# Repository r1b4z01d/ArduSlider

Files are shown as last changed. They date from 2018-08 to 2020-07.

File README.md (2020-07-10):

*ArduSlider
** Arduino:
*** API:
The arduino expects each api call to consist of a letter (flag), set of numbers and a charige return. Example: B1000/n
In Flags: 
	T: Length of session in milliseconds
		T60000/n
	S: Sutter speed in milliseconds 
		S1000/n
	B: Length of time the cammera takes to save the image and clear it's buffer in milliseconds.
		B3000/n
	D: Distance of travel for the session in mm
		D1000/n
	R: Boolen trigger to start/stop the session.
		R1/n
	A: Request a full refresh of all parameters
		A/n 

Out:

  sendData("T",String(msOfCapture));
  sendData("P",String(photo));
  sendData("C",String(numPhotos));
  sendData("R",String(isRunning));
  sendData("S",String(shutterSpeed));
  sendData("B",String(bufferClear));
  sendData("D",String(mmOfTravel));
  sendData("L",String(totalSteps));

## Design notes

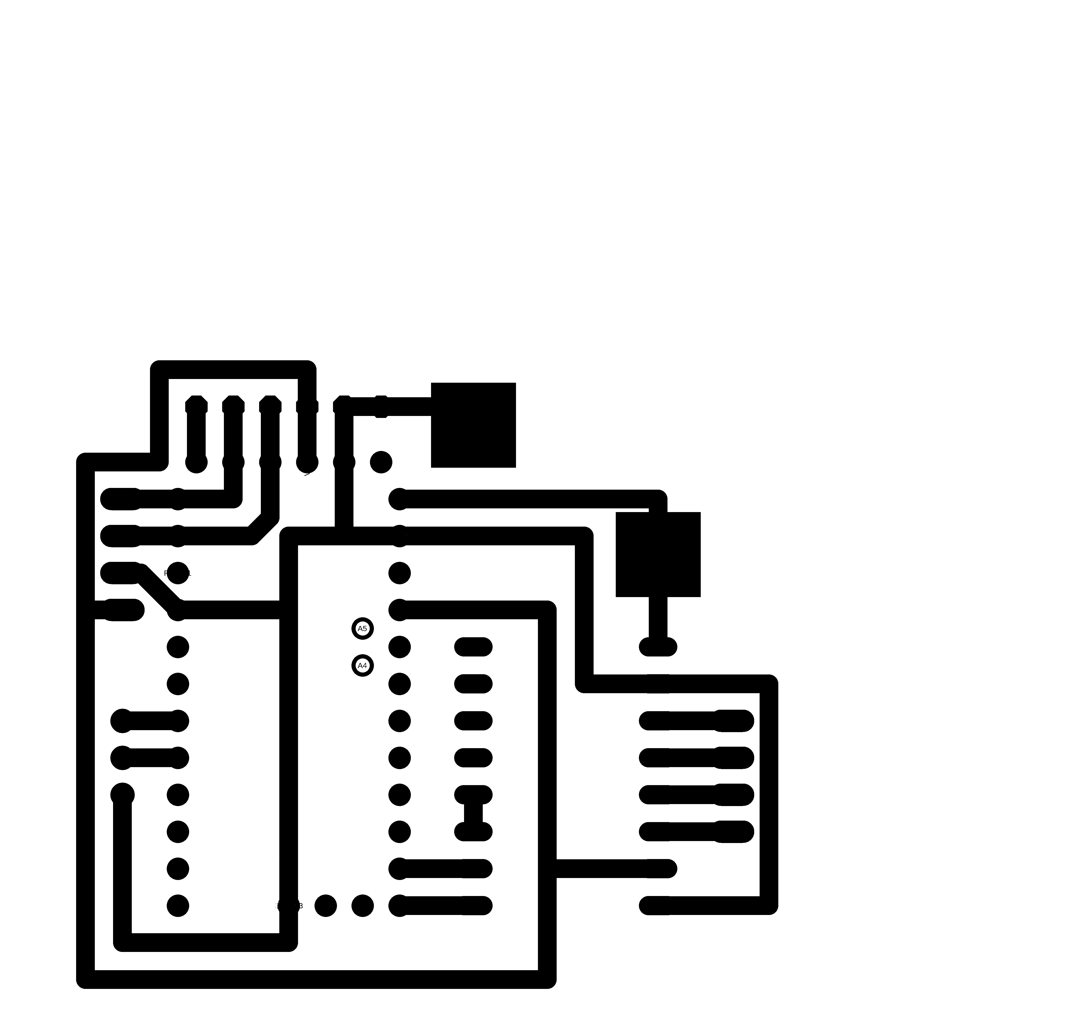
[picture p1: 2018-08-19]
PCB/pcb.png

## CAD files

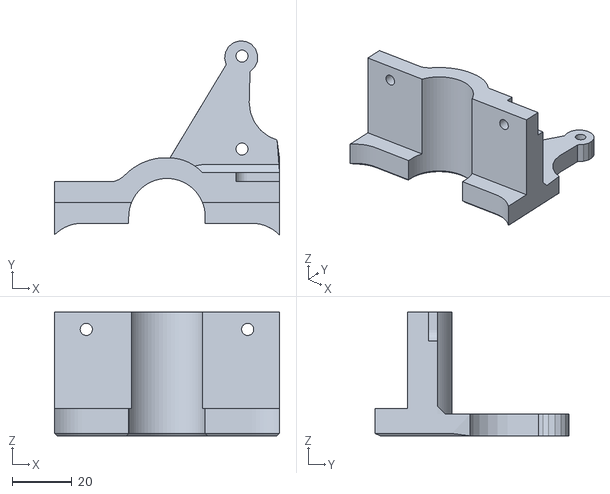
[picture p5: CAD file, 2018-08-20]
3D Models/MPCNCRemixA.stl
75.0 x 64.8 x 41.3

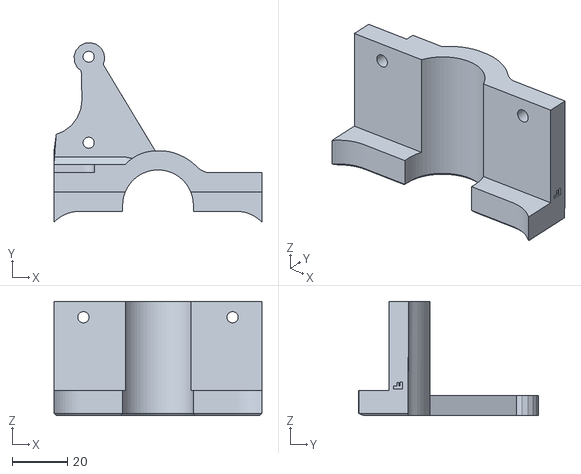
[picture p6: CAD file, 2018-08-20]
3D Models/MPCNCRemixR.stl
75.0 x 64.8 x 41.3

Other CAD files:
3D Models/MPCNCRemix.skp

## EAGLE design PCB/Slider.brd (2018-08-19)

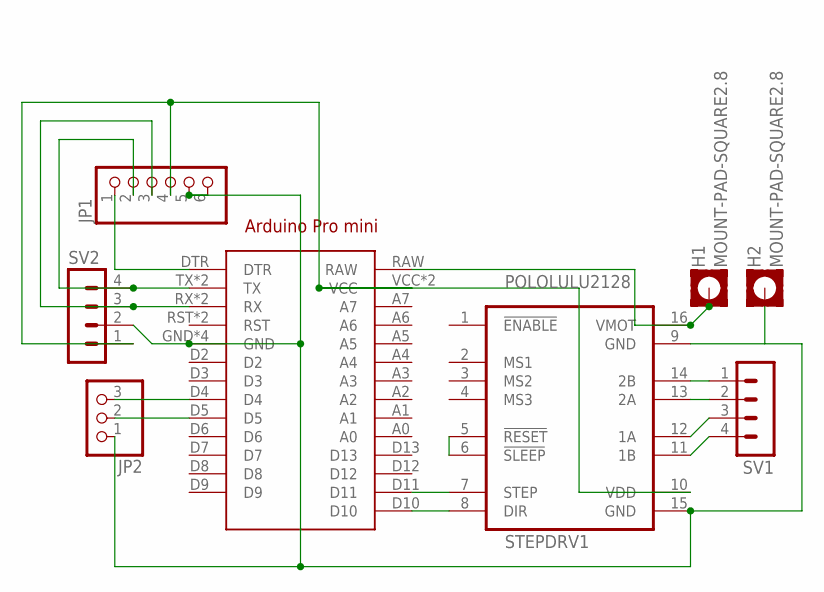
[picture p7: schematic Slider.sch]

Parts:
ARDUINO1: ARDUINO_PRO_MINI
H1, H2: MOUNT-PAD-SQUARE2.8; 2,8-PAD-SQUARE
JP1: PINHD-1X6; 1X06
JP2: PINHD-1X3CB; 1X03-CLEANBIG
STEPDRV1: POLOLULU2128
SV1, SV2: MA04-1

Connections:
unnamed: ARDUINO1.D11, STEPDRV1.7 (STEP)
unnamed: ARDUINO1.D10, STEPDRV1.8 (DIR)
unnamed: STEPDRV1.5 (!RESET), STEPDRV1.6 (!SLEEP)
unnamed: STEPDRV1.11 (1B), SV1.4
unnamed: STEPDRV1.12 (1A), SV1.3
unnamed: STEPDRV1.13 (2A), SV1.2
unnamed: STEPDRV1.14 (2B), SV1.1
unnamed: ARDUINO1.RAW, H1.B2,8, STEPDRV1.16 (VMOT)
unnamed: ARDUINO1.VCC, ARDUINO1.VCC@1 (VCC), JP1.4, STEPDRV1.10 (VDD), SV2.1
unnamed: ARDUINO1.GND, ARDUINO1.GND@1 (GND), ARDUINO1.GND@2 (GND), ARDUINO1.GND@3 (GND), H2.B2,8, JP1.5, JP1.6, JP2.1, STEPDRV1.9 (GND), STEPDRV1.15 (GND), SV2.2
unnamed: ARDUINO1.DTR, JP1.1
unnamed: ARDUINO1.RX, ARDUINO1.RX@1 (RX), JP1.3, SV2.3
unnamed: ARDUINO1.TX, ARDUINO1.TX@1 (TX), JP1.2, SV2.4
unnamed: ARDUINO1.D4, JP2.3
unnamed: ARDUINO1.D5, JP2.2

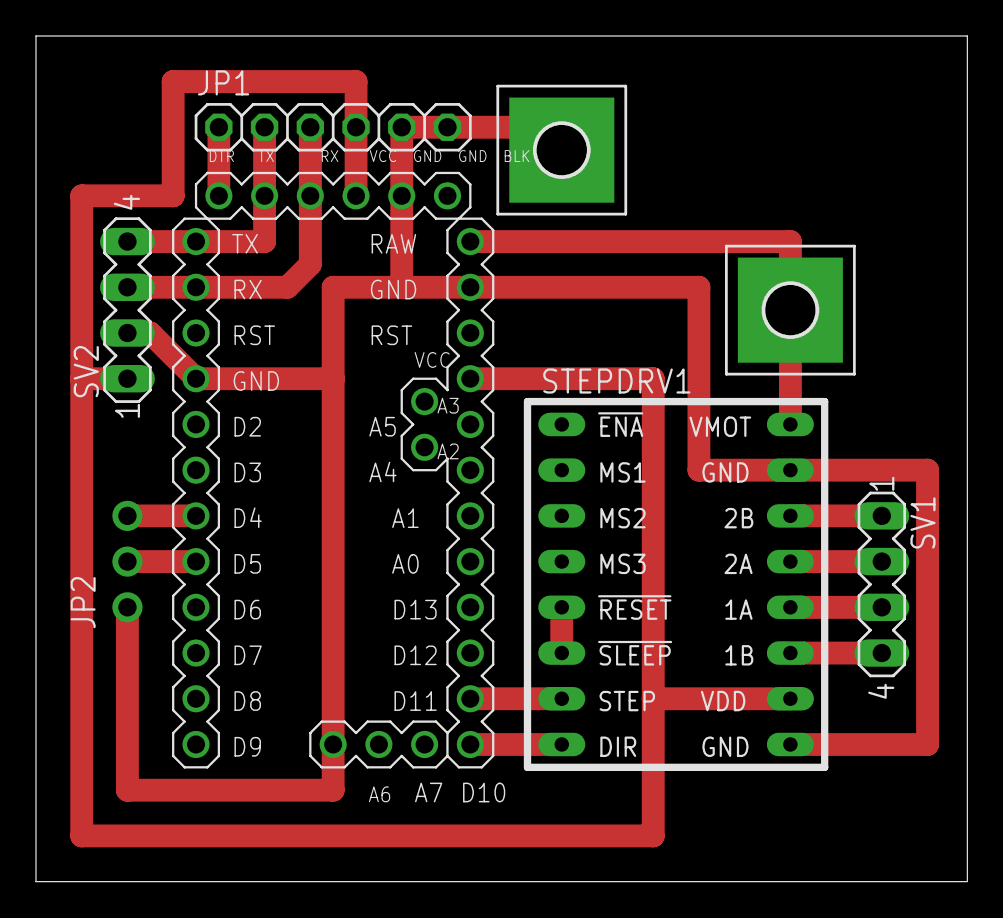
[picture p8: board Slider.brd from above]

Board: 2 copper layers, 51.7 x 47.0 mm, 8 parts (0 on the bottom side), 15 nets.

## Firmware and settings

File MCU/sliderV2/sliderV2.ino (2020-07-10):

// defines pins numbers
const int stepPin = 10; 
const int dirPin = 9; 
const int shutterPin = 2;
const int ledPin = 13;

int incomingByte = 0;   // for incoming serial data
// system config
int shutterSpeed = 200;
int bufferClear = 3000;
int shakeSettle = 1000;
int stepsPerMM = 4;
float msOfCapture = 60000;
int mmOfTravel = 8000;
int isRunning = 0;

//derived variables 
int traversalDirection=1;//TODPO
int videoLength = 0;
int stepsPerPhoto = 0;
int photo = 1;
float numPhotos = 0;
int totalSteps = 0;
void setup() {
  // Sets the two pins as Outputs
  pinMode(stepPin,OUTPUT); 
  pinMode(dirPin,OUTPUT);
  pinMode(shutterPin,OUTPUT); 
  pinMode(ledPin,OUTPUT); 
  Serial.begin(9600);
  sendDataRefresh();
}

void takePhoto(){
    digitalWrite(shutterPin,HIGH);
    digitalWrite(ledPin,HIGH);  
    delay(200); 
    digitalWrite(shutterPin,LOW); 
    digitalWrite(ledPin,LOW); 
    delay(200);
    Serial.print("Taking Photo Number: "); 
    Serial.println(photo);
    sendData("P",String(photo));
}

void moveCamera(){
    Serial.print("Moving the camera ");
    Serial.print(stepsPerPhoto);
    Serial.println(" steps.");
    //set motor direction 
    digitalWrite(dirPin,HIGH);
    //move the motor
    for(int steps=0;steps<=stepsPerPhoto;steps++){
      digitalWrite(stepPin,HIGH); 
      delayMicroseconds(500); 
      digitalWrite(stepPin,LOW); 
      delayMicroseconds(500);
      Serial.print("Moving step:");
      Serial.println(steps);
      totalSteps++;
      delayMicroseconds(1000);
    }
    Serial.println("Waiting for the shake to settle.");
    sendData("L",String(totalSteps));
    delay(shakeSettle);
}

void calcParams(){
  numPhotos=msOfCapture/(shutterSpeed+bufferClear+shakeSettle);
  stepsPerPhoto=(mmOfTravel*stepsPerMM)/numPhotos;
  videoLength=numPhotos/24;
}

void parseData(){
  String theData;
  int dataFlag;

  dataFlag = Serial.read();
  while (Serial.available() > 0) {
    // read the incoming byte:
    incomingByte = Serial.read();
    theData.concat(char(incomingByte));
  }

  switch (dataFlag) {
    case 'T':// Time to capture in seconds
      msOfCapture = theData.toFloat();
      break;
    case 'S':// Shutter speed in ms
      shutterSpeed = theData.toInt();
      break;
    case 'B':// Time to clear camera buffer in ms
      bufferClear = theData.toInt();
      break;
    case 'D':// Distance to travel in mm
      mmOfTravel = theData.toInt();
      break;
    case 'R':// Distance to travel in mm
      isRunning = theData.toInt();
      photo = 1;
      sendDataRefresh();
      break;
    case 'A':// Send Data Refresh
      sendDataRefresh();
      break;

  }
  //send an update
  sendDataRefresh();
}

void sendData(String flag, String data){
  Serial.println(flag+data);
}

void sendDataRefresh(){
  sendData("T",String(msOfCapture));
  sendData("P",String(photo));
  sendData("C",String(numPhotos));
  sendData("R",String(isRunning));
  sendData("S",String(shutterSpeed));
  sendData("B",String(bufferClear));
  sendData("D",String(mmOfTravel));
  sendData("L",String(totalSteps));
  sendData("V",String(videoLength));
  sendData("A",String(stepsPerPhoto));
}
  
void loop() {
  delay(500);
  if(Serial.available() > 0){//data in buffer
    parseData();//parse incoming data 
  }
  calcParams();  
  while(photo<=numPhotos&&Serial.available()==0&&isRunning==1){       
    takePhoto();//take photo
    delay(shutterSpeed+bufferClear);//wait for photo to take and save.
    photo++;//increment current photo take
    moveCamera();//Move Camera
    delay(shakeSettle);//wait for shaking to stop   
  }
}

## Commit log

2018-08-19 WIP 1st test print
    [MPCNCRemix.skp, MPCNCRemix.stl]
2018-08-19 PCB, Android & Arduino Code
    [Slider.brd, Slider.sch]
2018-08-20 thickened motor mount and lowered base
    [MPCNCRemix.skp, MPCNCRemix.stl, MPCNCRemix~.skp]
2018-08-20 left & right plus improvements
    [MPCNCRemix.skp, MPCNCRemix.stl, MPCNCRemixA.stl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]
